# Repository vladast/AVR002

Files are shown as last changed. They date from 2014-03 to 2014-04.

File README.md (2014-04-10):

# AVR-based event recorder with USB support

Event recorder device based on AVR processor, with the USB support enabled via V-USB library.

* **Project code name**: Fisherman's Friend
* **Homepage**: https://github.com/vladast/avr-based-event-recorder-with-usb-support

## Hardware

Key components of the hardware implementation are:
* **Atmel's Atmega8 processor**: a heart of the device, within which all logic lies.
* **ST's 24c64 EEPROM**: a persistent memory of the device.

Schematic diagram and PCB outline are created with Eagle v6 and can be found within **hw** directory.

## Software

Software part of the project consist of two parts:
* **Firmware**: a program being uploaded to device.
* **Test application**: a program running on host machine.

Programming languages used: C & C++.

Source code is located within **sw** directory.

## Configuration

There are couple of properties that have to be updated within Makefile before build can be started - following values should be set correctly:
* **PROGRAMMER**: By default, it states *rs232* which is the programmer used on test circuit. It should be set to the programmer's name from avrdude's configuration.
* **USB_CFG_VENDOR_ID**: USB VID 16bit value (see Makefile comments for more info, or refer to V-USB's site)
* **USB_CFG_DEVICE_ID**: USB PID 16bit value (see Makefile comments for more info, or refer to V-USB's site)
* **USB_CFG_VENDOR_NAME**: Name of the vendor. By default, for testing purposes, it's set to "TEST"
* **USB_CFG_VENDOR_NAME_LEN**: Number of chars within your vendor's name. For "TEST" string, that number is 4.
* **USB_CFG_DEVICE_NAME**: Name of your product. By default, for testing purposes, it's set to "TEST"
* **USB_CFG_DEVICE_NAME_LEN**: Number of chars within your vendor's name. For "TEST" string, that number is 4.

## Build procedure

At this moment, Makefile has only been intended for usage on Linux-based build machines with gcc and avr-gcc compilers installed. 
In general, with some modifications, it can be used on other platforms.

To build both firmware and test application run:

```
make build
```

To build only device's firmware (HEX file):

```
make build_hex
```

And to build only test application for host machine:

```
make build_test
```

To list all options from Makefile, run:

```
make
```

## Uploading firmware onto device

Used Makefile is configured for usage of *avrdude* programmer. To upload firmware to AVR located on device run:

```
make burn_firmware
```

**Note**: To use external crystal oscillator, for AVR chip used (which is Atmega8 at this moment), fuses has to be set first. To do so, run:

```
make burn_fuses
```

Of course, both of those commands should be issued as is from **sw** directory.

## 3rd party libraries

Following libraries were used:

* **V-USB**: A firmware-only USB driver for Atmel AVR Microcontrollers, enabling USB communication with host device. Library itself and documentation can be found on www.obdev.at/vusb/. 
V-USB is licensed under GPL version 2.
* **24C EEPROM SPI**: Enables easy SPI communication with external EEPROM. It's usage is well described on http://extremeelectronics.co.in/avr-tutorials/easy-24c-i2c-serial-eeprom-interfacing-with-avr-microcontrollers/

## Author and Licence

**avr-based-event-recorder-with-usb-support** repository is maintained by *Vladimir Stankovic*.

This project is licensed under *GPL Version 2*. Please, refer to LICENSE file for the full text of the license.

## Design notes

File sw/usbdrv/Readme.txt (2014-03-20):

This is the Readme file to Objective Development's firmware-only USB driver
for Atmel AVR microcontrollers. For more information please visit
http://www.obdev.at/vusb/

This directory contains the USB firmware only. Copy it as-is to your own
project and add all .c and .S files to your project (these files are marked
with an asterisk in the list below). Then copy usbconfig-prototype.h as
usbconfig.h to your project and edit it according to your configuration.

TECHNICAL DOCUMENTATION
=======================
The technical documentation (API) for the firmware driver is contained in the
file "usbdrv.h". Please read all of it carefully! Configuration options are
documented in "usbconfig-prototype.h".

The driver consists of the following files:
  Readme.txt ............. The file you are currently reading.
  Changelog.txt .......... Release notes for all versions of the driver.
  usbdrv.h ............... Driver interface definitions and technical docs.
* usbdrv.c ............... High level language part of the driver. Link this
                           module to your code!
* usbdrvasm.S ............ Assembler part of the driver. This module is mostly
                           a stub and includes one of the usbdrvasm*.S files
                           depending on processor clock. Link this module to
                           your code!
  usbdrvasm*.inc ......... Assembler routines for particular clock frequencies.
                           Included by usbdrvasm.S, don't link it directly!
  asmcommon.inc .......... Common assembler routines. Included by
                           usbdrvasm*.inc, don't link it directly!
  usbconfig-prototype.h .. Prototype for your own usbdrv.h file.
* oddebug.c .............. Debug functions. Only used when DEBUG_LEVEL is
                           defined to a value greater than 0. Link this module
                           to your code!
  oddebug.h .............. Interface definitions of the debug module.
  usbportability.h ....... Header with compiler-dependent stuff.
  usbdrvasm.asm .......... Compatibility stub for IAR-C-compiler. Use this
                           module instead of usbdrvasm.S when you assembler
                           with IAR's tools.
  License.txt ............ Open Source license for this driver.
  CommercialLicense.txt .. Optional commercial license for this driver.
  USB-ID-FAQ.txt ......... General infos about USB Product- and Vendor-IDs.
  USB-IDs-for-free.txt ... List and terms of use for free shared PIDs.

(*) ... These files should be linked to your project.

CPU CORE CLOCK FREQUENCY
========================
We supply assembler modules for clock frequencies of 12 MHz, 12.8 MHz, 15 MHz,
16 MHz, 16.5 MHz 18 MHz and 20 MHz. Other clock rates are not supported. The
actual clock rate must be configured in usbconfig.h.

12 MHz Clock
This is the traditional clock rate of V-USB because it's the lowest clock
rate where the timing constraints of the USB spec can be met.

15 MHz Clock
Similar to 12 MHz, but some NOPs inserted. On the other hand, the higher clock
rate allows for some loops which make the resulting code size somewhat smaller
than the 12 MHz version.

16 MHz Clock
This clock rate has been added for users of the Arduino board and other
ready-made boards which come with a fixed 16 MHz crystal. It's also an option
if you need the slightly higher clock rate for performance reasons. Since
16 MHz is not divisible by the USB low speed bit clock of 1.5 MHz, the code
is somewhat tricky and has to insert a leap cycle every third byte.

12.8 MHz and 16.5 MHz Clock
The assembler modules for these clock rates differ from the other modules
because they have been built for an RC oscillator with only 1% precision. The
receiver code inserts leap cycles to compensate for clock deviations. 1% is
also the precision which can be achieved by calibrating the internal RC
oscillator of the AVR. Please note that only AVRs with internal 64 MHz PLL
oscillator can reach 16.5 MHz with the RC oscillator. This includes the very
popular ATTiny25, ATTiny45, ATTiny85 series as well as the ATTiny26. Almost
all AVRs can reach 12.8 MHz, although this is outside the specified range.

See the EasyLogger example at http://www.obdev.at/vusb/easylogger.html for
code which calibrates the RC oscillator based on the USB frame clock.

18 MHz Clock
This module is closer to the USB specification because it performs an on the
fly CRC check for incoming packets. Packets with invalid checksum are
discarded as required by the spec. If you also implement checks for data
PID toggling on application level (see option USB_CFG_CHECK_DATA_TOGGLING
in usbconfig.h for more info), this ensures data integrity. Due to the CRC
tables and alignment requirements, this code is bigger than modules for other
clock rates. To activate this module, you must define USB_CFG_CHECK_CRC to 1
and USB_CFG_CLOCK_KHZ to 18000 in usbconfig.h.

20 MHz Clock
This module is for people who won't do it with less than the maximum. Since
20 MHz is not divisible by the USB low speed bit clock of 1.5 MHz, the code
uses similar tricks as the 16 MHz module to insert leap cycles.

USB IDENTIFIERS
===============
Every USB device needs a vendor- and a product-identifier (VID and PID). VIDs
are obtained from usb.org for a price of 1,500 USD. Once you have a VID, you
can assign PIDs at will.

Since an entry level cost of 1,500 USD is too high for most small companies
and hobbyists, we provide some VID/PID pairs for free. See the file
USB-IDs-for-free.txt for details.

Objective Development also has some license offerings which include product
IDs. See http://www.obdev.at/vusb/ for details.

DEVELOPMENT SYSTEM
==================
This driver has been developed and optimized for the GNU compiler version 3
and 4. We recommend that you use the GNU compiler suite because it is freely
available. V-USB has also been ported to the IAR compiler and assembler. It
has been tested with IAR 4.10B/W32 and 4.12A/W32 on an ATmega8 with the
"small" and "tiny" memory model. Not every release is tested with IAR CC and
the driver may therefore fail to compile with IAR. Please note that gcc is
more efficient for usbdrv.c because this module has been deliberately
optimized for gcc.

Gcc version 3 produces smaller code than version 4 due to new optimizing
capabilities which don't always improve things on 8 bit CPUs. The code size
generated by gcc 4 can be reduced with the compiler options
-fno-move-loop-invariants, -fno-tree-scev-cprop and
-fno-inline-small-functions in addition to -Os. On devices with more than
8k of flash memory, we also recommend the linker option --relax (written as
-Wl,--relax for gcc) to convert absolute calls into relative where possible.

For more information about optimizing options see:

    http://www.tty1.net/blog/2008-04-29-avr-gcc-optimisations_en.html

These optimizations are good for gcc 4.x. Version 3.x of gcc does not support
most of these options and produces good code anyway.

USING V-USB FOR FREE
====================
The AVR firmware driver is published under the GNU General Public License
Version 2 (GPL2) and the GNU General Public License Version 3 (GPL3). It is
your choice whether you apply the terms of version 2 or version 3.

If you decide for the free GPL2 or GPL3, we STRONGLY ENCOURAGE you to do the
following things IN ADDITION to the obligations from the GPL:

(1) Publish your entire project on a web site and drop us a note with the URL.
Use the form at http://www.obdev.at/vusb/feedback.html for your submission.
If you don't have a web site, you can publish the project in obdev's
documentation wiki at
http://www.obdev.at/goto.php?t=vusb-wiki&p=hosted-projects.

(2) Adhere to minimum publication standards. Please include AT LEAST:
    - a circuit diagram in PDF, PNG or GIF format
    - full source code for the host software
    - a Readme.txt file in ASCII format which describes the purpose of the
      project and what can be found in which directories and which files
    - a reference to http://www.obdev.at/vusb/

(3) If you improve the driver firmware itself, please give us a free license
to your modifications for our commercial license offerings.

COMMERCIAL LICENSES FOR V-USB
=============================
If you don't want to publish your source code under the terms of the GPL,
you can simply pay money for V-USB. As an additional benefit you get
USB PIDs for free, reserved exclusively to you. See the file
"CommercialLicense.txt" for details.

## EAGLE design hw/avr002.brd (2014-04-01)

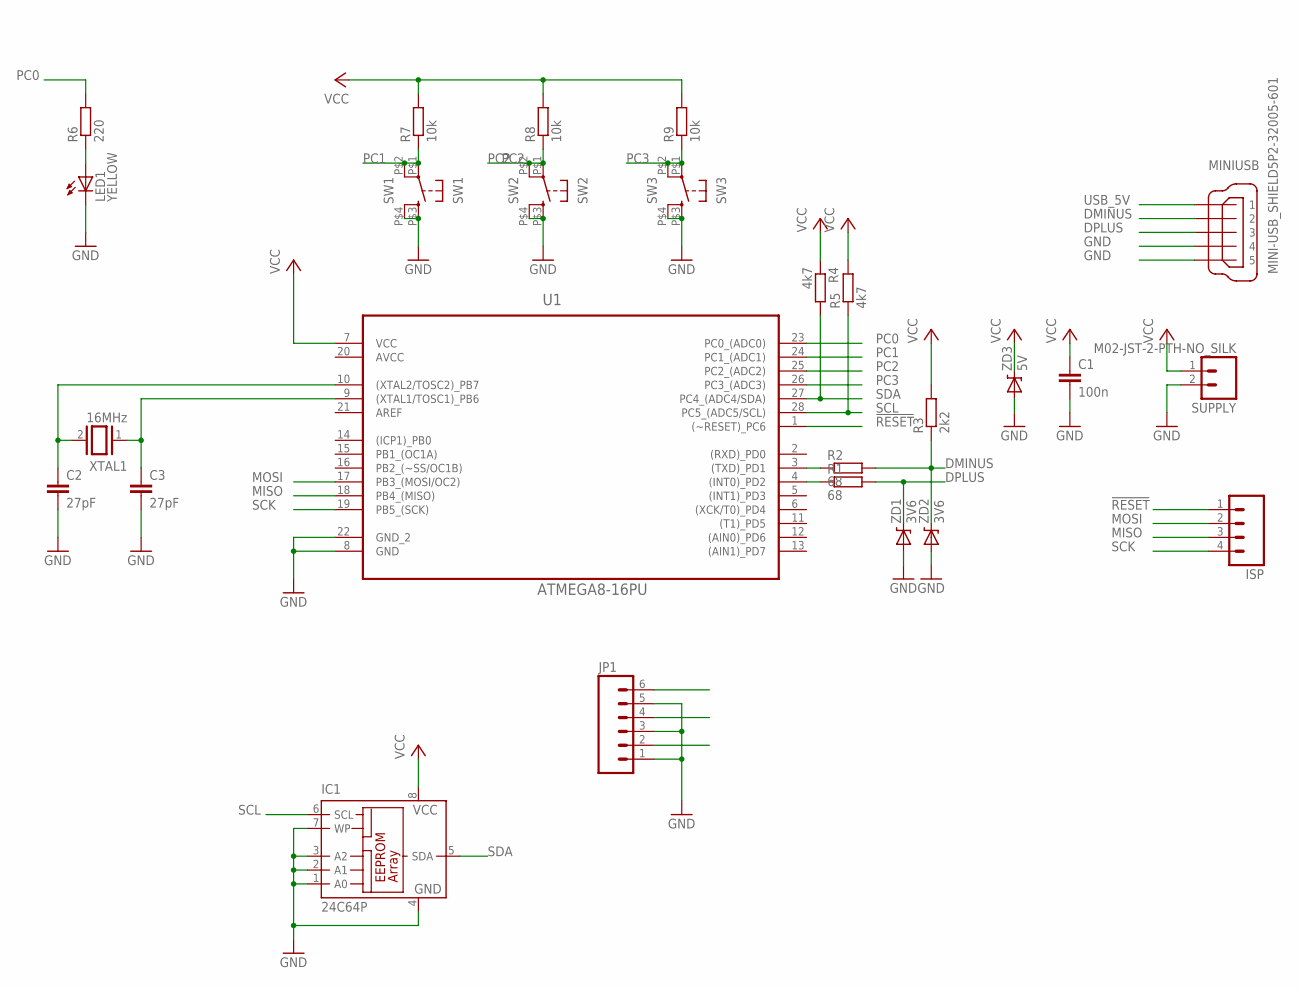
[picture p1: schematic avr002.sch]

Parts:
C1: 100n; C050-024X044
C2, C3: 27pF; C050-024X044
IC1: 24C64P; DIL8
ISP: M04POLAR; MOLEX-1X4
JP1: M06POLAR; MOLEX-1X6
LED1: YELLOW; LED5MM
MINIUSB: MINI-USB_SHIELD5P2-32005-601; 32005-601
R1, R2: 68; 0204/7
R3: 2k2; 0204/7
R4, R5: 4k7; 0204/7
R6: 220; 0204/7
R7, R8, R9: 10k; 0204/7
SUPPLY: M02-JST-2-PTH-NO_SILK; JST-2-PTH-NS
SW1: SW1; KSA_SEALED_TAC_SWITCH
SW2: SW2; KSA_SEALED_TAC_SWITCH
SW3: SW3; KSA_SEALED_TAC_SWITCH
U1: ATMEGA8-16PU; DIP254P762X457-28
XTAL1: 16MHz; Q
ZD1, ZD2: 3V6; DIODE-ZENER
ZD3: 5V; DIODE-ZENER

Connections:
!RESET: ISP.1, U1.1 ((~RESET)_PC6)
AVCC: U1.20 (AVCC)
DMINUS: MINIUSB.2, R2.2, R3.1, ZD2.P$1 (C)
DPLUS: MINIUSB.3, R1.2, ZD1.P$1 (C)
GND: C1.2, C2.2, C3.2, IC1.1 (A0), IC1.2 (A1), IC1.3 (A2), IC1.4 (GND), IC1.7 (WP), JP1.1, JP1.3, JP1.5, LED1.K (C), MINIUSB.4, MINIUSB.5, SUPPLY.2, SW1.P$3 (3), SW1.P$4 (4), SW2.P$3 (3), SW2.P$4 (4), SW3.P$3 (3), SW3.P$4 (4), U1.8 (GND), U1.22 (GND_2), ZD1.P$2 (A), ZD2.P$2 (A), ZD3.P$2 (A)
MISO: ISP.3, U1.18 (PB4_(MISO))
MOSI: ISP.2, U1.17 (PB3_(MOSI/OC2))
unnamed: R1.1, U1.4 ((INT0)_PD2)
unnamed: R2.1, U1.3 ((TXD)_PD1)
unnamed: C2.1, U1.10 ((XTAL2/TOSC2)_PB7), XTAL1.2
unnamed: C3.1, U1.9 ((XTAL1/TOSC1)_PB6), XTAL1.1
unnamed: LED1.A, R6.1
PC0: R6.2, U1.23 (PC0_(ADC0))
PC1: JP1.2, R7.1, SW1.P$1 (1), SW1.P$2 (2), U1.24 (PC1_(ADC1))
PC2: JP1.4, R8.1, SW2.P$1 (1), SW2.P$2 (2), U1.25 (PC2_(ADC2))
PC3: JP1.6, R9.1, SW3.P$1 (1), SW3.P$2 (2), U1.26 (PC3_(ADC3))
SCK: ISP.4, U1.19 (PB5_(SCK))
SCL: IC1.6 (SCL), R5.1, U1.28 (PC5_(ADC5/SCL))
SDA: IC1.5 (SDA), R4.2, U1.27 (PC4_(ADC4/SDA))
USB_5V: MINIUSB.1
VCC: C1.1, IC1.8 (VCC), R3.2, R4.1, R5.2, R7.2, R8.2, R9.2, SUPPLY.1, U1.7 (VCC), ZD3.P$1 (C)

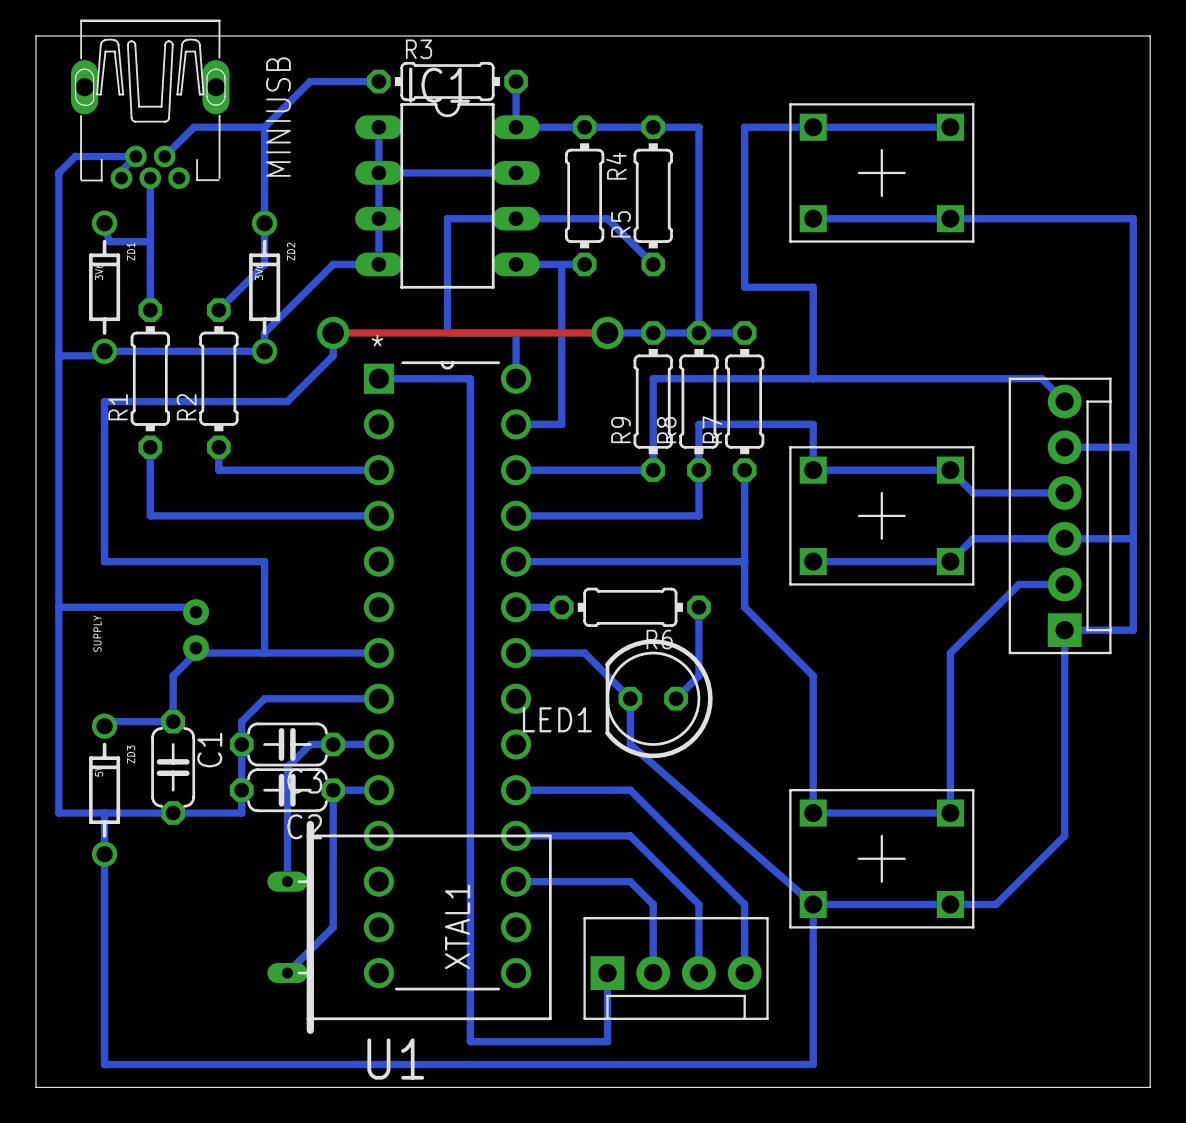
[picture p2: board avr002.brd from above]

Board: 2 copper layers, 61.9 x 58.4 mm, 26 parts (0 on the bottom side), 19 nets.

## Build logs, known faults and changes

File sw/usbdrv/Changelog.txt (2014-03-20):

This file documents changes in the firmware-only USB driver for atmel's AVR
microcontrollers. New entries are always appended to the end of the file.
Scroll down to the bottom to see the most recent changes.

2005-04-01:
  - Implemented endpoint 1 as interrupt-in endpoint.
  - Moved all configuration options to usbconfig.h which is not part of the
    driver.
  - Changed interface for usbVendorSetup().
  - Fixed compatibility with ATMega8 device.
  - Various minor optimizations.

2005-04-11:
  - Changed interface to application: Use usbFunctionSetup(), usbFunctionRead()
    and usbFunctionWrite() now. Added configuration options to choose which
    of these functions to compile in.
  - Assembler module delivers receive data non-inverted now.
  - Made register and bit names compatible with more AVR devices.

2005-05-03:
  - Allow address of usbRxBuf on any memory page as long as the buffer does
    not cross 256 byte page boundaries.
  - Better device compatibility: works with Mega88 now.
  - Code optimization in debugging module.
  - Documentation updates.

2006-01-02:
  - Added (free) default Vendor- and Product-IDs bought from voti.nl.
  - Added USBID-License.txt file which defines the rules for using the free
    shared VID/PID pair.
  - Added Readme.txt to the usbdrv directory which clarifies administrative
    issues.

2006-01-25:
  - Added "configured state" to become more standards compliant.
  - Added "HALT" state for interrupt endpoint.
  - Driver passes the "USB Command Verifier" test from usb.org now.
  - Made "serial number" a configuration option.
  - Minor optimizations, we now recommend compiler option "-Os" for best
    results.
  - Added a version number to usbdrv.h

2006-02-03:
  - New configuration variable USB_BUFFER_SECTION for the memory section where
    the USB rx buffer will go. This defaults to ".bss" if not defined. Since
    this buffer MUST NOT cross 256 byte pages (not even touch a page at the
    end), the user may want to pass a linker option similar to
    "-Wl,--section-start=.mybuffer=0x800060".
  - Provide structure for usbRequest_t.
  - New defines for USB constants.
  - Prepared for HID implementations.
  - Increased data size limit for interrupt transfers to 8 bytes.
  - New macro usbInterruptIsReady() to query interrupt buffer state.

2006-02-18:
  - Ensure that the data token which is sent as an ack to an OUT transfer is
    always zero sized. This fixes a bug where the host reports an error after
    sending an out transfer to the device, although all data arrived at the
    device.
  - Updated docs in usbdrv.h to reflect changed API in usbFunctionWrite().

* Release 2006-02-20

  - Give a compiler warning when compiling with debugging turned on.
  - Added Oleg Semyonov's changes for IAR-cc compatibility.
  - Added new (optional) functions usbDeviceConnect() and usbDeviceDisconnect()
    (also thanks to Oleg!).
  - Rearranged tests in usbPoll() to save a couple of instructions in the most
    likely case that no actions are pending.
  - We need a delay between the SET ADDRESS request until the new address
    becomes active. This delay was handled in usbPoll() until now. Since the
    spec says that the delay must not exceed 2ms, previous versions required
    aggressive polling during the enumeration phase. We have now moved the
    handling of the delay into the interrupt routine.
  - We must not reply with NAK to a SETUP transaction. We can only achieve this
    by making sure that the rx buffer is empty when SETUP tokens are expected.
    We therefore don't pass zero sized data packets from the status phase of
    a transfer to usbPoll(). This change MAY cause troubles if you rely on
    receiving a less than 8 bytes long packet in usbFunctionWrite() to
    identify the end of a transfer. usbFunctionWrite() will NEVER be called
    with a zero length.

* Release 2006-03-14

  - Improved IAR C support: tiny memory model, more devices
  - Added template usbconfig.h file under the name usbconfig-prototype.h

* Release 2006-03-26

  - Added provision for one more interrupt-in endpoint (endpoint 3).
  - Added provision for one interrupt-out endpoint (endpoint 1).
  - Added flowcontrol macros for USB.
  - Added provision for custom configuration descriptor.
  - Allow ANY two port bits for D+ and D-.
  - Merged (optional) receive endpoint number into global usbRxToken variable.
  - Use USB_CFG_IOPORTNAME instead of USB_CFG_IOPORT. We now construct the
    variable name from the single port letter instead of computing the address
    of related ports from the output-port address.

* Release 2006-06-26

  - Updated documentation in usbdrv.h and usbconfig-prototype.h to reflect the
    new features.
  - Removed "#warning" directives because IAR does not understand them. Use
    unused static variables instead to generate a warning.
  - Do not include <avr/io.h> when compiling with IAR.
  - Introduced USB_CFG_DESCR_PROPS_* in usbconfig.h to configure how each
    USB descriptor should be handled. It is now possible to provide descriptor
    data in Flash, RAM or dynamically at runtime.
  - STALL is now a status in usbTxLen* instead of a message. We can now conform
    to the spec and leave the stall status pending until it is cleared.
  - Made usbTxPacketCnt1 and usbTxPacketCnt3 public. This allows the
    application code to reset data toggling on interrupt pipes.

* Release 2006-07-18

  - Added an #if !defined __ASSEMBLER__ to the warning in usbdrv.h. This fixes
    an assembler error.
  - usbDeviceDisconnect() takes pull-up resistor to high impedance now.

* Release 2007-02-01

  - Merged in some code size improvements from usbtiny (thanks to Dick
    Streefland for these optimizations!)
  - Special alignment requirement for usbRxBuf not required any more. Thanks
    again to Dick Streefland for this hint!
  - Reverted to "#warning" instead of unused static variables -- new versions
    of IAR CC should handle this directive.
  - Changed Open Source license to GNU GPL v2 in order to make linking against
    other free libraries easier. We no longer require publication of the
    circuit diagrams, but we STRONGLY encourage it. If you improve the driver
    itself, PLEASE grant us a royalty free license to your changes for our
    commercial license.

* Release 2007-03-29

  - New configuration option "USB_PUBLIC" in usbconfig.h.
  - Set USB version number to 1.10 instead of 1.01.
  - Code used USB_CFG_DESCR_PROPS_STRING_DEVICE and
    USB_CFG_DESCR_PROPS_STRING_PRODUCT inconsistently. Changed all occurrences
    to USB_CFG_DESCR_PROPS_STRING_PRODUCT.
  - New assembler module for 16.5 MHz RC oscillator clock with PLL in receiver
    code.
  - New assembler module for 16 MHz crystal.
  - usbdrvasm.S contains common code only, clock-specific parts have been moved
    to usbdrvasm12.S, usbdrvasm16.S and usbdrvasm165.S respectively.

* Release 2007-06-25

  - 16 MHz module: Do SE0 check in stuffed bits as well.

* Release 2007-07-07

  - Define hi8(x) for IAR compiler to limit result to 8 bits. This is necessary
    for negative values.
  - Added 15 MHz module contributed by V. Bosch.
  - Interrupt vector name can now be configured. This is useful if somebody
    wants to use a different hardware interrupt than INT0.

* Release 2007-08-07

  - Moved handleIn3 routine in usbdrvasm16.S so that relative jump range is
    not exceeded.
  - More config options: USB_RX_USER_HOOK(), USB_INITIAL_DATATOKEN,
    USB_COUNT_SOF
  - USB_INTR_PENDING can now be a memory address, not just I/O

* Release 2007-09-19

  - Split out common parts of assembler modules into separate include file
  - Made endpoint numbers configurable so that given interface definitions
    can be matched. See USB_CFG_EP3_NUMBER in usbconfig-prototype.h.
  - Store endpoint number for interrupt/bulk-out so that usbFunctionWriteOut()
    can handle any number of endpoints.
  - Define usbDeviceConnect() and usbDeviceDisconnect() even if no
    USB_CFG_PULLUP_IOPORTNAME is defined. Directly set D+ and D- to 0 in this
    case.

* Release 2007-12-01

  - Optimize usbDeviceConnect() and usbDeviceDisconnect() for less code size
    when USB_CFG_PULLUP_IOPORTNAME is not defined.

* Release 2007-12-13

  - Renamed all include-only assembler modules from *.S to *.inc so that
    people don't add them to their project sources.
  - Distribute leap bits in tx loop more evenly for 16 MHz module.
  - Use "macro" and "endm" instead of ".macro" and ".endm" for IAR
  - Avoid compiler warnings for constant expr range by casting some values in
    USB descriptors.

* Release 2008-01-21

  - Fixed bug in 15 and 16 MHz module where the new address set with
    SET_ADDRESS was already accepted at the next NAK or ACK we send, not at
    the next data packet we send. This caused problems when the host polled
    too fast. Thanks to Alexander Neumann for his help and patience debugging
    this issue!

* Release 2008-02-05

  - Fixed bug in 16.5 MHz module where a register was used in the interrupt
    handler before it was pushed. This bug was introduced with version
    2007-09-19 when common parts were moved to a separate file.
  - Optimized CRC routine (thanks to Reimar Doeffinger).

* Release 2008-02-16

  - Removed outdated IAR compatibility stuff (code sections).
  - Added hook macros for USB_RESET_HOOK() and USB_SET_ADDRESS_HOOK().
  - Added optional routine usbMeasureFrameLength() for calibration of the
    internal RC oscillator.

* Release 2008-02-28

  - USB_INITIAL_DATATOKEN defaults to USBPID_DATA1 now, which means that we
    start with sending USBPID_DATA0.
  - Changed defaults in usbconfig-prototype.h
  - Added free USB VID/PID pair for MIDI class devices
  - Restructured AVR-USB as separate package, not part of PowerSwitch any more.

* Release 2008-04-18

  - Restructured usbdrv.c so that it is easier to read and understand.
  - Better code optimization with gcc 4.
  - If a second interrupt in endpoint is enabled, also add it to config
    descriptor.
  - Added config option for long transfers (above 254 bytes), see
    USB_CFG_LONG_TRANSFERS in usbconfig.h.
  - Added 20 MHz module contributed by Jeroen Benschop.

* Release 2008-05-13

  - Fixed bug in libs-host/hiddata.c function usbhidGetReport(): length
    was not incremented, pointer to length was incremented instead.
  - Added code to command line tool(s) which claims an interface. This code
    is disabled by default, but may be necessary on newer Linux kernels.
  - Added usbconfig.h option "USB_CFG_CHECK_DATA_TOGGLING".
  - New header "usbportability.h" prepares ports to other development
    environments.
  - Long transfers (above 254 bytes) did not work when usbFunctionRead() was
    used to supply the data. Fixed this bug. [Thanks to Alexander Neumann!]
  - In hiddata.c (example code for sending/receiving data over HID), use
    USB_RECIP_DEVICE instead of USB_RECIP_INTERFACE for control transfers so
    that we need not claim the interface.
  - in usbPoll() loop 20 times polling for RESET state instead of 10 times.
    This accounts for the higher clock rates we now support.
  - Added a module for 12.8 MHz RC oscillator with PLL in receiver loop.
  - Added hook to SOF code so that oscillator can be tuned to USB frame clock.
  - Added timeout to waitForJ loop. Helps preventing unexpected hangs.
  - Added example code for oscillator tuning to libs-device (thanks to
    Henrik Haftmann for the idea to this routine).
  - Implemented option USB_CFG_SUPPRESS_INTR_CODE.

* Release 2008-10-22

  - Fixed libs-device/osctune.h: OSCCAL is memory address on ATMega88 and
    similar, not offset of 0x20 needs to be added.
  - Allow distribution under GPLv3 for those who have to link against other
    code distributed under GPLv3.

* Release 2008-11-26

  - Removed libusb-win32 dependency for hid-data example in Makefile.windows.
    It was never required and confused many people.
  - Added extern uchar usbRxToken to usbdrv.h.
  - Integrated a module with CRC checks at 18 MHz by Lukas Schrittwieser.

* Release 2009-03-23

  - Hid-mouse example used settings from hid-data example, fixed that.
  - Renamed project to V-USB due to a trademark issue with Atmel(r).
  - Changed CommercialLicense.txt and USBID-License.txt to make the
    background of USB ID registration clearer.

* Release 2009-04-15

  - Changed CommercialLicense.txt to reflect the new range of PIDs from
    Jason Kotzin.
  - Removed USBID-License.txt in favor of USB-IDs-for-free.txt and
    USB-ID-FAQ.txt
  - Fixed a bug in the 12.8 MHz module: End Of Packet decection was made in
    the center between bit 0 and 1 of each byte. This is where the data lines
    are expected to change and the sampled data may therefore be nonsense.
    We therefore check EOP ONLY if bits 0 AND 1 have both been read as 0 on D-.
  - Fixed a bitstuffing problem in the 16 MHz module: If bit 6 was stuffed,
    the unstuffing code in the receiver routine was 1 cycle too long. If
    multiple bytes had the unstuffing in bit 6, the error summed up until the
    receiver was out of sync.
  - Included option for faster CRC routine.
    Thanks to Slawomir Fras (BoskiDialer) for this code!
  - Updated bits in Configuration Descriptor's bmAttributes according to
    USB 1.1 (in particular bit 7, it is a must-be-set bit now).

* Release 2009-08-22

  - Moved first DBG1() after odDebugInit() in all examples.
  - Use vector INT0_vect instead of SIG_INTERRUPT0 if defined. This makes
    V-USB compatible with the new "p" suffix devices (e.g. ATMega328p).
  - USB_CFG_CLOCK_KHZ setting is now required in usbconfig.h (no default any
    more).
  - New option USB_CFG_DRIVER_FLASH_PAGE allows boot loaders on devices with
    more than 64 kB flash.
  - Built-in configuration descriptor allows custom definition for second
    endpoint now.

* Release 2010-07-15

  - Fixed bug in usbDriverSetup() which prevented descriptor sizes above 255
    bytes.
  - Avoid a compiler warning for unused parameter in usbHandleResetHook() when
    compiler option -Wextra is enabled.
  - Fixed wrong hex value for some IDs in USB-IDs-for-free.txt.
  - Keep a define for USBATTR_BUSPOWER, although the flag does not exist
    in USB 1.1 any more. Set it to 0. This is for backward compatibility.

* Release 2012-01-09

  - Define a separate (defined) type for usbMsgPtr so that projects using a
    tiny memory model can define it to an 8 bit type in usbconfig.h. This
    change also saves a couple of bytes when using a scalar 16 bit type.
  - Inserted "const" keyword for all PROGMEM declarations because new GCC
    requires it.
  - Fixed problem with dependence of usbportability.h on usbconfig.h. This
    problem occurred with IAR CC only.
  - Prepared repository for github.com.

* Release 2012-12-06

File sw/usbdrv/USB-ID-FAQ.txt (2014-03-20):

Version 2012-07-09

==========================
WHY DO WE NEED THESE IDs?
==========================

USB is more than a low level protocol for data transport. It also defines a
common set of requests which must be understood by all devices. And as part
of these common requests, the specification defines data structures, the
USB Descriptors, which are used to describe the properties of the device.

From the perspective of an operating system, it is therefore possible to find
out basic properties of a device (such as e.g. the manufacturer and the name
of the device) without a device-specific driver. This is essential because
the operating system can choose a driver to load based on this information
(Plug-And-Play).

Among the most important properties in the Device Descriptor are the USB
Vendor- and Product-ID. Both are 16 bit integers. The most simple form of
driver matching is based on these IDs. The driver announces the Vendor- and
Product-IDs of the devices it can handle and the operating system loads the
appropriate driver when the device is connected.

It is obvious that this technique only works if the pair Vendor- plus
Product-ID is unique: Only devices which require the same driver can have the
same pair of IDs.

=====================================================
HOW DOES THE USB STANDARD ENSURE THAT IDs ARE UNIQUE?
=====================================================

Since it is so important that USB IDs are unique, the USB Implementers Forum,
Inc. (usb.org) needs a way to enforce this legally. It is not forbidden by
law to build a device and assign it any random numbers as IDs. Usb.org
therefore needs an agreement to regulate the use of USB IDs. The agreement
binds only parties who agreed to it, of course. Everybody else is free to use
any numbers for their IDs.

So how can usb.org ensure that every manufacturer of USB devices enters into
an agreement with them? They do it via trademark licensing. Usb.org has
registered the trademark "USB", all associated logos and related terms. If
you want to put an USB logo on your product or claim that it is USB
compliant, you must license these trademarks from usb.org. And this is where
you enter into an agreement. See the "USB-IF Trademark License Agreement and
Usage Guidelines for the USB-IF Logo" at
http://www.usb.org/developers/logo_license/.

Licensing the USB trademarks requires that you buy a USB Vendor-ID from
usb.org (one-time fee of ca. 2,000 USD), that you become a member of usb.org
(yearly fee of ca. 4,000 USD) and that you meet all the technical
specifications from the USB spec.

This means that most hobbyists and small companies will never be able to
become USB compliant, just because membership is so expensive. And you can't
be compliant with a driver based on V-USB anyway, because the AVR's port pins
don't meet the electrical specifications for USB. So, in principle, all
hobbyists and small companies are free to choose any random numbers for their
IDs. They have nothing to lose...

There is one exception worth noting, though: If you use a sub-component which
implements USB, the vendor of the sub-components may guarantee USB
compliance. This might apply to some or all of FTDI's solutions.

=======================================================================
WHY SHOULD YOU OBTAIN USB IDs EVEN IF YOU DON'T LICENSE USB TRADEMARKS?
=======================================================================

You have learned in the previous section that you are free to choose any
numbers for your IDs anyway. So why not do exactly this? There is still the
technical issue. If you choose IDs which are already in use by somebody else,
operating systems will load the wrong drivers and your device won't work.
Even if you choose IDs which are not currently in use, they may be in use in
the next version of the operating system or even after an automatic update.

So what you need is a pair of Vendor- and Product-IDs for which you have the
guarantee that no USB compliant product uses them. This implies that no
operating system will ever ship with drivers responsible for these IDs.

==============================================
HOW DOES OBJECTIVE DEVELOPMENT HANDLE USB IDs?
==============================================

Objective Development gives away pairs of USB-IDs with their V-USB licenses.
In order to ensure that these IDs are unique, Objective Development has an
agreement with the company/person who has bought the USB Vendor-ID from
usb.org. This agreement ensures that a range of USB Product-IDs is reserved
for assignment by Objective Development and that the owner of the Vendor-ID
won't give it to anybody else.

This means that you have to trust three parties to ensure uniqueness of
your IDs:

  - Objective Development, that they don't give the same PID to more than
    one person.
  - The owner of the Vendor-ID that they don't assign PIDs from the range
    assigned to Objective Development to anybody else.
  - Usb.org that they don't assign the same Vendor-ID a second time.

==================================
WHO IS THE OWNER OF THE VENDOR-ID?
==================================

Objective Development has obtained ranges of USB Product-IDs under two
Vendor-IDs: Under Vendor-ID 5824 from Wouter van Ooijen (Van Ooijen
Technische Informatica, www.voti.nl) and under Vendor-ID 8352 from Jason
Kotzin (now flirc.tv, Inc.). Both VID owners have received their Vendor-ID
directly from usb.org.

=========================================================================
CAN I USE USB-IDs FROM OBJECTIVE DEVELOPMENT WITH OTHER DRIVERS/HARDWARE?
=========================================================================

The short answer is: Yes. All you get is a guarantee that the IDs are never
assigned to anybody else. What more do you need?

============================
WHAT ABOUT SHARED ID PAIRS?
============================

Objective Development has reserved some PID/VID pairs for shared use. You
have no guarantee of uniqueness for them, except that no USB compliant device
uses them. In order to avoid technical problems, we must ensure that all
devices with the same pair of IDs use the same driver on kernel level. For
details, see the file USB-IDs-for-free.txt.

======================================================
I HAVE HEARD THAT SUB-LICENSING OF USB-IDs IS ILLEGAL?
======================================================

A 16 bit integer number cannot be protected by copyright laws. It is not
sufficiently complex. And since none of the parties involved entered into the
USB-IF Trademark License Agreement, we are not bound by this agreement. So
there is no reason why it should be illegal to sub-license USB-IDs.

=============================================
WHO IS LIABLE IF THERE ARE INCOMPATIBILITIES?
=============================================

Objective Development disclaims all liabilities which might arise from the
assignment of IDs. If you guarantee product features to your customers
without proper disclaimer, YOU are liable for that.

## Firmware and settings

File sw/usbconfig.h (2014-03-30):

/* Name: usbconfig.h
 * Project: V-USB, virtual USB port for Atmel's(r) AVR(r) microcontrollers
 * Author: Christian Starkjohann
 * Creation Date: 2005-04-01
 * Tabsize: 4
 * Copyright: (c) 2005 by OBJECTIVE DEVELOPMENT Software GmbH
 * License: GNU GPL v2 (see License.txt under usbdrv directory), GNU GPL v3 or proprietary (CommercialLicense.txt)
 */

#ifndef __usbconfig_h_included__
#define __usbconfig_h_included__

/*
General Description:
This file is an example configuration (with inline documentation) for the USB
driver. It configures V-USB for USB D+ connected to Port D bit 2 (which is
also hardware interrupt 0 on many devices) and USB D- to Port D bit 4. You may
wire the lines to any other port, as long as D+ is also wired to INT0 (or any
other hardware interrupt, as long as it is the highest level interrupt, see
section at the end of this file).
*/

/* ---------------------------- Hardware Config ---------------------------- */

#define USB_CFG_IOPORTNAME      D
/* This is the port where the USB bus is connected. When you configure it to
 * "B", the registers PORTB, PINB and DDRB will be used.
 */
#define USB_CFG_DMINUS_BIT      1
/* This is the bit number in USB_CFG_IOPORT where the USB D- line is connected.
 * This may be any bit in the port.
 */
#define USB_CFG_DPLUS_BIT       2
/* This is the bit number in USB_CFG_IOPORT where the USB D+ line is connected.
 * This may be any bit in the port. Please note that D+ must also be connected
 * to interrupt pin INT0! [You can also use other interrupts, see section
 * "Optional MCU Description" below, or you can connect D- to the interrupt, as
 * it is required if you use the USB_COUNT_SOF feature. If you use D- for the
 * interrupt, the USB interrupt will also be triggered at Start-Of-Frame
 * markers every millisecond.]
 */
#define USB_CFG_CLOCK_KHZ       (F_CPU/1000)
/* Clock rate of the AVR in kHz. Legal values are 12000, 12800, 15000, 16000,
 * 16500, 18000 and 20000. The 12.8 MHz and 16.5 MHz versions of the code
 * require no crystal, they tolerate +/- 1% deviation from the nominal
 * frequency. All other rates require a precision of 2000 ppm and thus a
 * crystal!
 * Since F_CPU should be defined to your actual clock rate anyway, you should
 * not need to modify this setting.
 */
#define USB_CFG_CHECK_CRC       0
/* Define this to 1 if you want that the driver checks integrity of incoming
 * data packets (CRC checks). CRC checks cost quite a bit of code size and are
 * currently only available for 18 MHz crystal clock. You must choose
 * USB_CFG_CLOCK_KHZ = 18000 if you enable this option.
 */

/* ----------------------- Optional Hardware Config ------------------------ */

//#define USB_CFG_PULLUP_IOPORTNAME   A // vladast //
/* If you connect the 1.5k pullup resistor from D- to a port pin instead of
 * V+, you can connect and disconnect the device from firmware by calling
 * the macros usbDeviceConnect() and usbDeviceDisconnect() (see usbdrv.h).
 * This constant defines the port on which the pullup resistor is connected.
 */
//#define USB_CFG_PULLUP_BIT          1 // vladast //
/* This constant defines the bit number in USB_CFG_PULLUP_IOPORT (defined
 * above) where the 1.5k pullup resistor is connected. See description
 * above for details.
 */

/* --------------------------- Functional Range ---------------------------- */
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

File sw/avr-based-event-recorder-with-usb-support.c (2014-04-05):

/*
 * Copyright (C) 2014  Vladimir Stankovic
 *
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
 * You should have received a copy of the GNU General Public License
 * along with this program.  If not, see <http://www.gnu.org/licenses/>
 */

#include <avr/io.h>
#include <avr/wdt.h>
#include <avr/interrupt.h>
#include <avr/eeprom.h>
#include <util/delay.h>

#include <avr/pgmspace.h>   /* required by usbdrv.h */
#include "usbdrv.h"
#include "oddebug.h"
#include "reqdefs.h"
#include "usbdefs.h"

#include "24c64.h"

#define TIMER1_PRESCALER_16384

#define SWITCH1             PINC1
#define SWITCH2             PINC2
#define SWITCH3             PINC3
#define STATUS              PORTC0

#define BUTTON_WITH         SWITCH1
#define BUTTON_THROW        SWITCH2
#define BUTTON_WITHOUT      SWITCH3

#define SWID_UNKNOWN        0x00
#define SWID_WITH           0x01
#define SWID_THROW          0x02
#define SWID_WITHOUT        0x03

#define REQ_GET_STATE       REQ_GET_DATA1
#define REQ_GET_SESSION     REQ_GET_DATA2
#define REQ_GET_ERROR       REQ_GET_DATA3

#define REQ_RESET_SESSION   REQ_SET_DATA2

// Predefined memory locations on CPU's EEPROM
#define MEMADDR_STATE       0x0000
#define MEMADDR_SESSION     0x0001
#define MEMADDR_ERROR       0x0002
#define MEMADDR_ENTRIES     0x0003

#define MEM_HW_ADDRESS      0x50

#define USB_CONNECT_CNT     5L      // Count 5 Timer1 interrupts
#define SWITCH_PRESS_CNT    50L     // Count 20 Timer0 interrupts

#define SAMPLING_TIME_WINDOW 1

#define FALSE   0
#define TRUE    1

volatile uint8_t    timer0_ticks;
volatile uint16_t   gCounter = 0;
volatile uint16_t   gPrevCounter = 0;
volatile uint16_t   gUsbConnectCounter;
volatile uint8_t    gOffsetCounter;
volatile uint8_t    gSessionCounter;
volatile uint16_t   gEntryCounter;
volatile uint16_t   gEventCounter;
//volatile uint8_t    gButtonLedCounter;
volatile short      isButtonWithPressed = FALSE;
volatile short      isButtonThrowPressed = FALSE;
volatile short      isButtonWithoutPressed = FALSE;
volatile short      isButtonLedOn = FALSE;
volatile short      isUsbConnectCounterStarted = FALSE;
volatile int        idPressedButton = SWID_UNKNOWN;
volatile short      isButtonValueReady = FALSE; // Returned to FALSE when written onto eeprom
short               isUsbInitialized = FALSE;
short               isStarted = FALSE;

volatile uint16_t   gEEpromCurrentAddress = 0;

//static uchar currAddress = 0;
//static uchar bytesRemaining = 0;


typedef enum
{
    START   = 0xa1, // Device is being started
    INIT    = 0xb2, // Initialize device
    RECORD  = 0xc3, // Record events (touch-switch states)
    UPLOAD  = 0xd4, // Upload records to USB host
    DELETE  = 0xe5, // Erase external EEPROM
    RESES   = 0xf6  // Reinit session counter
} state_t;

volatile state_t state = INIT;

/* ------------------------------------------------------------------------- */
/* ----------------------------- USB interface ----------------------------- */
/* ------------------------------------------------------------------------- */

int isPinPressed(int pin)
{
    return ((PINC & (1 << pin)) != (1 << pin)) ? TRUE : FALSE;
}

void initSession()
{
    uint8_t sessionCounter = 0;
    eeprom_write_block(&sessionCounter, MEMADDR_SESSION, 1);
    gSessionCounter = sessionCounter;
}

uint8_t readSession()
{
    uint8_t sessionCounter;
    eeprom_read_block(&sessionCounter, MEMADDR_SESSION, 1);
    return sessionCounter;
}

void createNewSession()
{
    uint8_t sessionCounter;

    while(!eeprom_is_ready());
    eeprom_read_block(&sessionCounter, MEMADDR_SESSION, 1);

    sessionCounter++;

    while(!eeprom_is_ready());
    eeprom_write_block(&sessionCounter, MEMADDR_SESSION, 1);
    gSessionCounter = sessionCounter;
}

uint16_t readEntryCount()
{
    eeprom_read_block(&gEntryCounter, MEMADDR_ENTRIES, 2);
    return gEntryCounter;
}

void storeEntryCount(uint16_t entryCount)
{
    gEntryCounter = entryCount;
    eeprom_write_block(&gEntryCounter, MEMADDR_ENTRIES, 2);
}

void initEntryCount()
{
    gEntryCounter = 0;
    storeEntryCount(gEntryCounter);
}

uint8_t readCurrentState()
{
    uint8_t currentState;
    eeprom_read_block(&currentState, MEMADDR_STATE, 1);
    return currentState;
}

void checkStartState()
{
    state_t startState;
    eeprom_read_block(&startState, MEMADDR_STATE, 1);

    // START   = 0xA1, // Device is being started
    // INIT    = 0xB2, // Initialize device
    // RECORD  = 0xC3, // Record events (touch-switch states)
    // UPLOAD  = 0xD4, // Upload records to USB host
    // DELETE  = 0xE5, // Erase external EEPROM
    // RESES   = 0xF6  // Reinit session counter

    if(startState != START && startState != INIT && startState != RECORD && startState != UPLOAD && startState != DELETE && startState != RESES)
    {
        // Upon start, no state was stored --> fresh start after session reset or reprogram!

        // NOTE: Use following line to store detected state; for start state troubleshooting purposes.
        //storeErrorCode(startState);

        //state = START;

        /* [Issue #2] temp fix */
        state = INIT;
        /* [Issue #2] temp fix */
    }
    else
    {
        state = INIT; // temp
    }

    /* [Issue #2] temp fix */
    if(readSession() == 0xff)
    {
        initSession();
    }
    /* [Issue #2] temp fix */

    /*else if (state == RECORD)
    {
        state = UPLOAD;
    }*/
}

void setCurrentState(state_t state_to_store)
{
    state = state_to_store;
    eeprom_write_block(&state, MEMADDR_STATE, 1);
}

uint8_t readErrorCode()
{
    uint8_t errorCode;
    eeprom_read_block(&errorCode, MEMADDR_ERROR, 1);
    return errorCode;
}

void storeErrorCode(uint8_t errorCode)
{
    eeprom_write_block(&errorCode, MEMADDR_ERROR, 1);
    return errorCode;
}
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

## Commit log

2014-03-20 Commented timer usage from avr001 project and removed oscillator calibration since crystal oscillator is going to be used
2014-03-20 Modified usbFunctionSetup to send SWITCH1 and SWITCH2 states
2014-03-21 Updated FUSE_L value to 0xEF
2014-03-21 Timer1 interrupt implemented - using comparison instead of overflow
2014-03-21 Removed unimplemented timer interrupts
2014-03-23 Added initialization of Timer0 and created interrupt handler for Timer0 overflows
2014-03-23 Implemented switch state detection in Timer0 interrupt
2014-03-26 Passing V-USB vendor/device defines via Makefile
2014-03-28 Implemented switch-state detection and signalization + 5secs detection of middle switch state, initiating UPLOAD state
2014-03-30 In the case that two touchswitches are pressed at the same time, break the processing of the event
2014-03-30 Removed redefined values that are already used by V-USB and defined DEVICE_CODE value for device distinction purposes
2014-04-01 Initial commit of Eagle files for the hardware
    [avr002.brd, avr002.sch]

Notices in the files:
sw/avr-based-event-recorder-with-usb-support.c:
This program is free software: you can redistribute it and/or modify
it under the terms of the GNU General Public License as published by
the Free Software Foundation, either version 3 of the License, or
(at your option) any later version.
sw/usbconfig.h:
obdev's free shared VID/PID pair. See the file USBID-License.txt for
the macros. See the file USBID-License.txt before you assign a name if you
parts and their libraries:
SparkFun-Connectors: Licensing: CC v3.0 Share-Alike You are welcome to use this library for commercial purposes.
